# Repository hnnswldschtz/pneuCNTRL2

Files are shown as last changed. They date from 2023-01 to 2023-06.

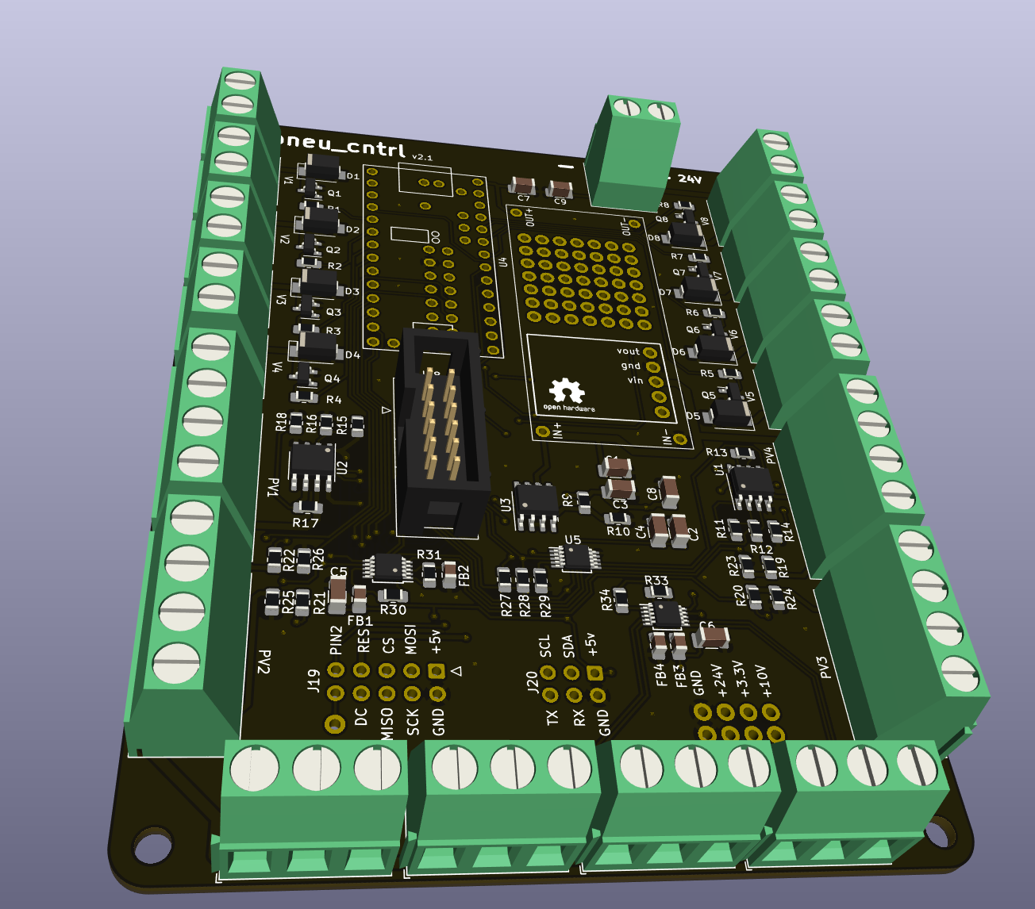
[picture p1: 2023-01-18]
hardware/pneuCNTRL.png

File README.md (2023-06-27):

# pneuCNTRL2 Firmware
8 channel pressure controlled inlation/deflation system for the inflatable haptics experiments

Setup:

- custom PCB released as openhardware under cern-ohl-w v2 license
- based on teensy3.2
- ads1115 for ADC
- MCP4728 for DAC
- 4x festo 571482 pressure sensors
- 4x smc 5/3 electric valves
- 4x Festo proportional piezo valves (VEAB-L-26-D7-Q4-V1-1R1)
- LCD i2c display

pneuCNTRL

libraries used:
ADS1115_lite: https://github.com/terryjmyers/ADS1115-Lite
Adafruit_MCP4728: https://github.com/adafruit/Adafruit_MCP4728
Adafruit_NeoPixel: https://github.com/adafruit/Adafruit_NeoPixel
LiquidCrystal_I2C: https://github.com/johnrickman/LiquidCrystal_I2C -> this gives a massive delay when used! maybe avoid!!
Adafruit_ADS1015: https://github.com/adafruit/Adafruit_ADS1X15

Bauhaus-University Weimar \
hnns 2022

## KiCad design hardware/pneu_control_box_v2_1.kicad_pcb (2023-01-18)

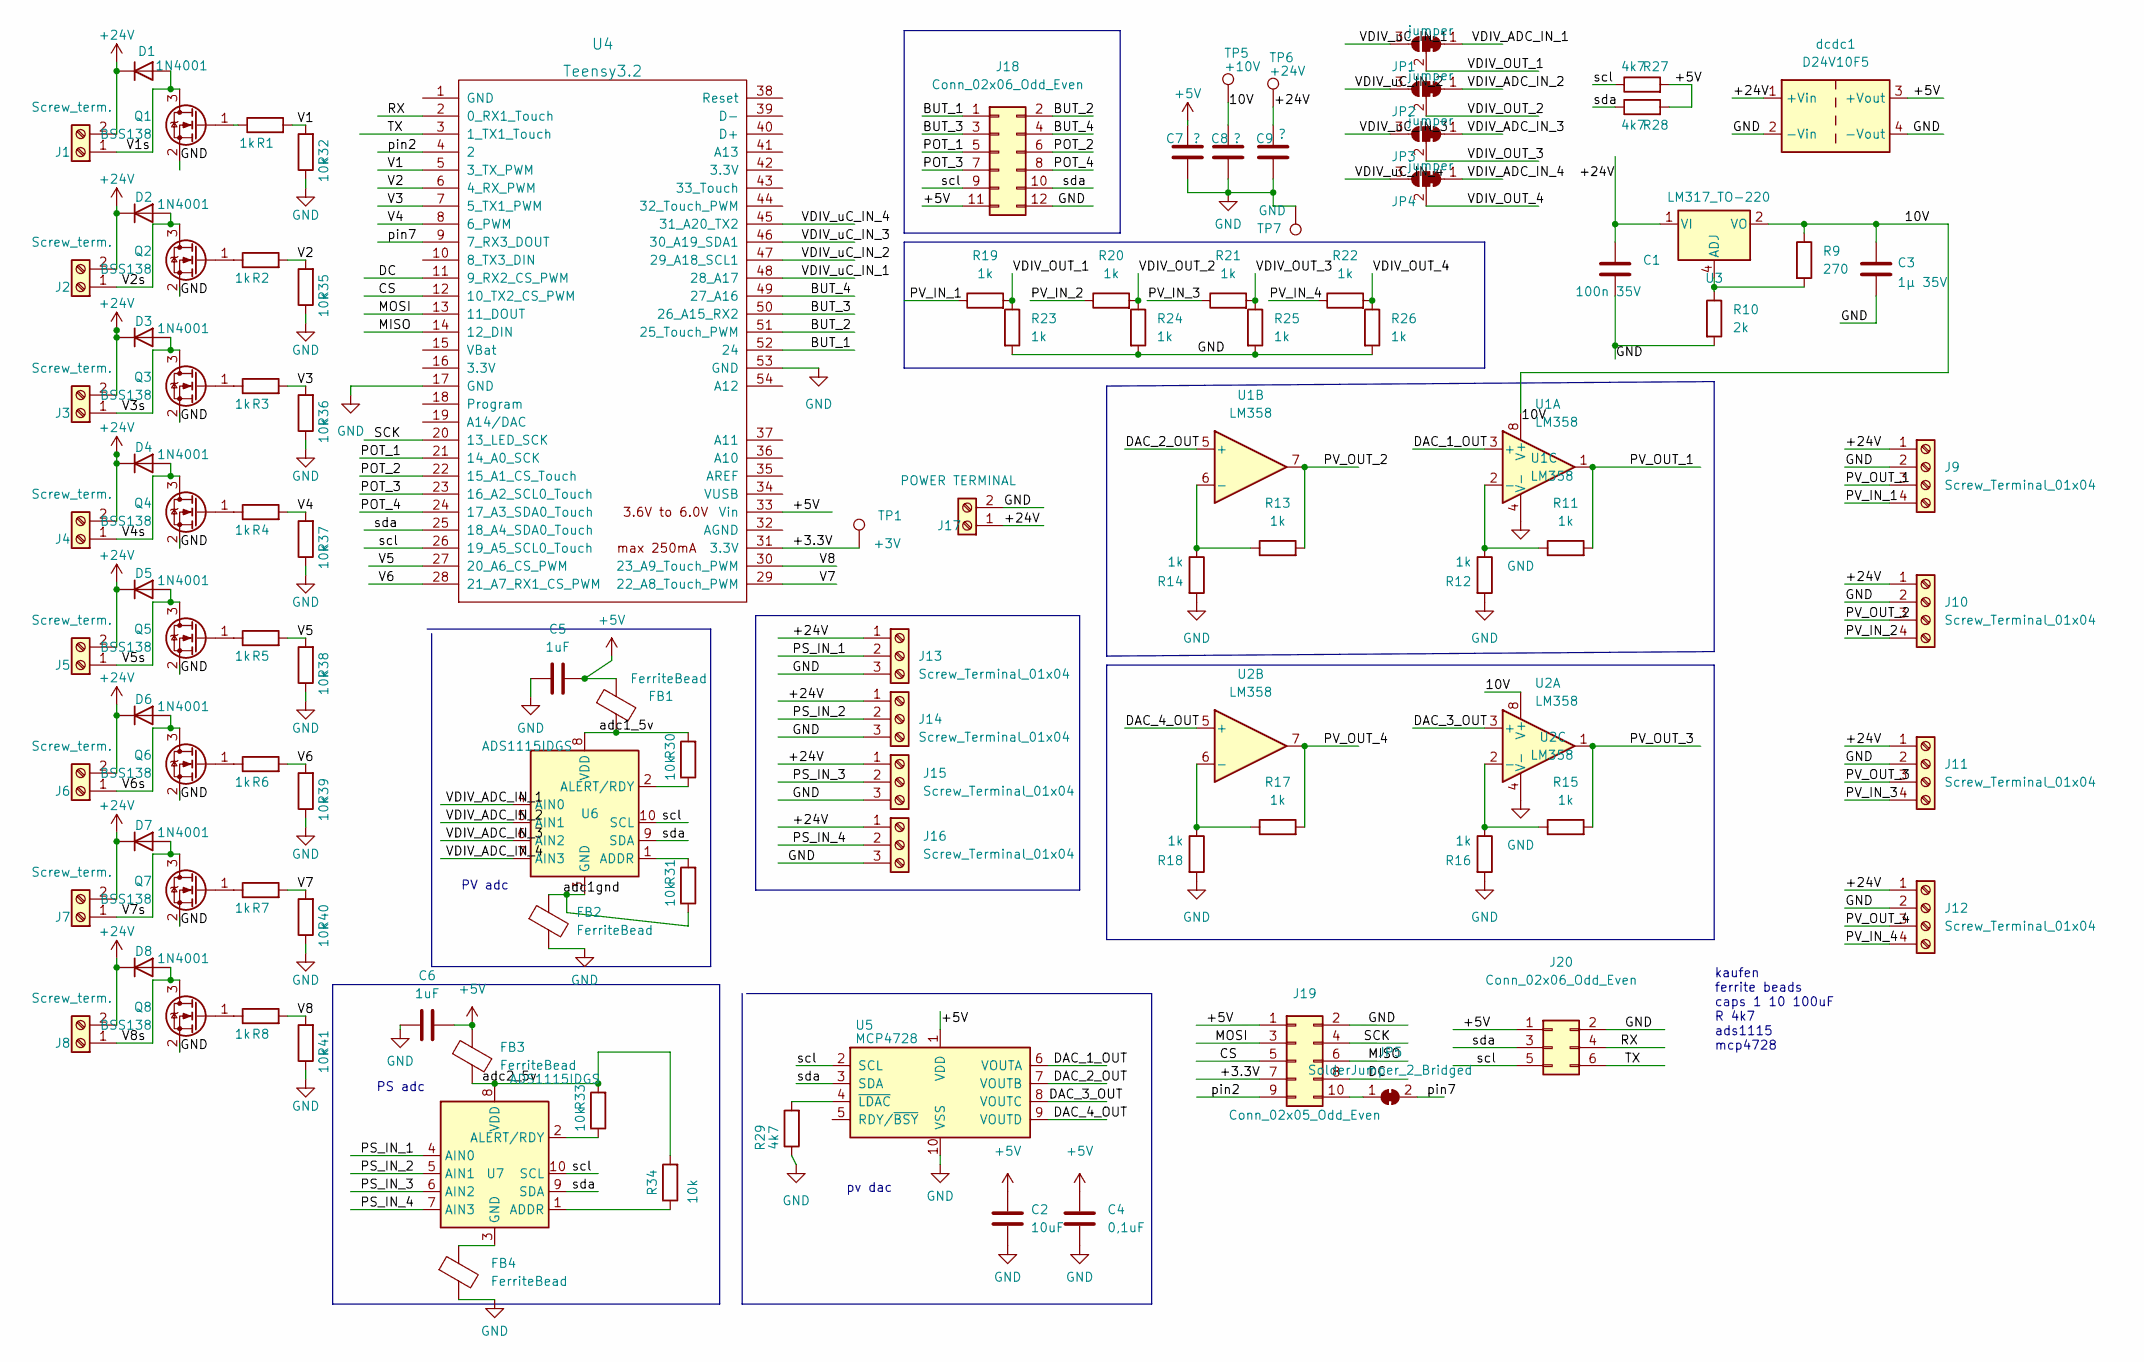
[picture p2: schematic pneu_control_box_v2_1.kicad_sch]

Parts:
C1: 100n 35V; C_1206_3216Metric
C2: 10uF; C_1206_3216Metric
C3: 1µ 35V; C_1206_3216Metric
C4: 0,1uF; C_1206_3216Metric
C5, C6: 1uF; C_1206_3216Metric
C7, C8, C9: ?; C_1206_3216Metric
D1, D2, D3, D4, D5, D6, D7, D8: 1N4001; D_SMA
FB1, FB2, FB3, FB4: FerriteBead; C_0805_2012Metric_Pad1.18x1.45mm_HandSolder
J1, J2, J3, J4, J5, J6, J7, J8: Screw_term.; TerminalBlock_Phoenix_MKDS-1,5-2_1x02_P5.00mm_Horizontal
J9, J10, J11, J12: Screw_Terminal_01x04; TerminalBlock_Phoenix_MKDS-1,5-4_1x04_P5.00mm_Horizontal
J13, J14, J15, J16: Screw_Terminal_01x04; TerminalBlock_Phoenix_MKDS-1,5-3_1x03_P5.00mm_Horizontal
J17: POWER TERMINAL; TerminalBlock_Phoenix_MKDS-1,5-2_1x02_P5.00mm_Horizontal
J18: Conn_02x06_Odd_Even; IDC-Header_2x06_P2.54mm_Vertical
J19: Conn_02x05_Odd_Even; IDC-Header_2x05_P2.54mm_Vertical
J20: Conn_02x06_Odd_Even; IDC-Header_2x03_P2.54mm_Vertical
JP1, JP2, JP3, JP4: jumper; SolderJumper-3_P1.3mm_Bridged12_Pad1.0x1.5mm
JP5: SolderJumper_2_Bridged; SolderJumper-2_P1.3mm_Bridged2Bar_Pad1.0x1.5mm
Q1, Q2, Q3, Q4, Q5, Q6, Q7, Q8: BSS138; SOT-23
R1, R2, R3, R4, R5, R6, R7, R8, R11, R12, R13, R14, R15, R16, R17, R18, R19, R20, R21, R22, R23, R24, R25, R26: 1k; R_0805_2012Metric_Pad1.20x1.40mm_HandSolder
R9: 270; R_0805_2012Metric_Pad1.20x1.40mm_HandSolder
R10: 2k; R_0805_2012Metric_Pad1.20x1.40mm_HandSolder
R27, R28, R29: 4k7; R_0805_2012Metric_Pad1.20x1.40mm_HandSolder
R30, R31, R32, R33, R34, R35, R36, R37, R38, R39, R40, R41: 10k; R_0805_2012Metric_Pad1.20x1.40mm_HandSolder
TP1: +3V; Pin_D1.0mm_L10.0mm
TP5: +10V; Pin_D1.0mm_L10.0mm
TP6: +24V; Pin_D1.0mm_L10.0mm
TP7: GND; Pin_D1.0mm_L10.0mm
U1, U2: LM358; SOIC-8_3.9x4.9mm_P1.27mm
U3: LM317_TO-220; SOIC-8_3.9x4.9mm_P1.27mm
U4: Teensy3.2; Teensy30_31_32_All_Pins
U5: MCP4728; MSOP-10_3x3mm_P0.5mm
U6, U7: ADS1115IDGS; TSSOP-10_3x3mm_P0.5mm
dcdc1: D24V10F5; LM2596 DC-DC

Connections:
+5V: C2.1, C4.1, C5.2, C6.2, C7.1, FB1.1, FB3.1, J18.11, J19.1, J20.1, R27.2, R28.2, U4.33 (Vin), U5.1 (VDD), dcdc1.3 (+Vout)
+24V: C1.1, C9.1, D1.1 (K), D2.1 (K), D3.1 (K), D4.1 (K), D5.1 (K), D6.1 (K), D7.1 (K), D8.1 (K), J1.2, J2.2, J3.2, J4.2, J5.2, J6.2, J7.2, J8.2, J9.1, J10.1, J11.1, J12.1, J13.1, J14.1, J15.1, J16.1, J17.1, TP6.1, U3.1 (VI), dcdc1.1 (+Vin); also elsewhere on the board
/10V: C3.1, C8.1, R9.1, TP5.1, U1.8 (V+), U2.8 (V+), U3.2 (VO), U3.3 (VI), U3.6 (VI), U3.7 (VI); also elsewhere on the board
/+3.3V: J19.7, TP1.1, U4.31 (3.3V); also elsewhere on the board
/BUT_1: J18.1, U4.52 (24)
/BUT_2: J18.2, U4.51 (25_Touch_PWM)
/BUT_3: J18.3, U4.50 (26_A15_RX2)
/BUT_4: J18.4, U4.49 (27_A16)
/CS: J19.5, U4.12 (10_TX2_CS_PWM)
/DAC_1_OUT: U1.3 (+), U5.6 (VOUTA)
/DAC_2_OUT: U1.5 (+), U5.7 (VOUTB)
/DAC_3_OUT: U2.3 (+), U5.8 (VOUTC)
/DAC_4_OUT: U2.5 (+), U5.9 (VOUTD)
/DC: J19.8, U4.11 (9_RX2_CS_PWM)
/MISO: J19.6, U4.14 (12_DIN)
/MOSI: J19.3, U4.13 (11_DOUT)
/POT_1: J18.5, U4.21 (14_A0_SCK)
/POT_2: J18.6, U4.22 (15_A1_CS_Touch)
/POT_3: J18.7, U4.23 (16_A2_SCL0_Touch)
/POT_4: J18.8, U4.24 (17_A3_SDA0_Touch)
/PS_IN_1: J13.2, U7.4 (AIN0)
/PS_IN_2: J14.2, U7.5 (AIN1)
/PS_IN_3: J15.2, U7.6 (AIN2)
/PS_IN_4: J16.2, U7.7 (AIN3)
/PV_IN_1: J9.4, R19.1
/PV_IN_2: J10.4, R20.1
/PV_IN_3: J11.4, R21.1
/PV_IN_4: J12.4, R22.1
/PV_OUT_1: J9.3, R11.2, U1.1
/PV_OUT_2: J10.3, R13.2, U1.7
/PV_OUT_3: J11.3, R15.2, U2.1
/PV_OUT_4: J12.3, R17.2, U2.7
/RX: J20.4, U4.2 (0_RX1_Touch)
/SCK: J19.4, U4.20 (13_LED_SCK)
/TX: J20.6, U4.3 (1_TX1_Touch)
/V1: R1.2, R32.2, U4.5 (3_TX_PWM)
/V1s: D1.2 (A), J1.1, Q1.3 (D)
/V2: R2.2, R35.2, U4.6 (4_RX_PWM)
/V2s: D2.2 (A), J2.1, Q2.3 (D)
/V3: R3.2, R36.2, U4.7 (5_TX1_PWM)
/V3s: D3.2 (A), J3.1, Q3.3 (D)
/V4: R4.2, R37.2, U4.8 (6_PWM)
/V4s: D4.2 (A), J4.1, Q4.3 (D)
/V5: R5.2, R38.2, U4.27 (20_A6_CS_PWM)
/V5s: D5.2 (A), J5.1, Q5.3 (D)
/V6: R6.2, R39.2, U4.28 (21_A7_RX1_CS_PWM)
/V6s: D6.2 (A), J6.1, Q6.3 (D)
/V7: R7.2, R40.2, U4.29 (22_A8_Touch_PWM)
/V7s: D7.2 (A), J7.1, Q7.3 (D)
/V8: R8.2, R41.2, U4.30 (23_A9_Touch_PWM)
/V8s: D8.2 (A), J8.1, Q8.3 (D)
/VDIV_ADC_IN_1: JP1.1 (A), U6.4 (AIN0)
/VDIV_ADC_IN_2: JP2.1 (A), U6.5 (AIN1)
/VDIV_ADC_IN_3: JP3.1 (A), U6.6 (AIN2)
/VDIV_ADC_IN_4: JP4.1 (A), U6.7 (AIN3)
/VDIV_OUT_1: JP1.2 (C), R19.2, R23.1
/VDIV_OUT_2: JP2.2 (C), R20.2, R24.1
/VDIV_OUT_3: JP3.2 (C), R21.2, R25.1
/VDIV_OUT_4: JP4.2 (C), R22.2, R26.1
/VDIV_uC_IN_1: JP1.3 (B), U4.48 (28_A17)
/VDIV_uC_IN_2: JP2.3 (B), U4.47 (29_A18_SCL1)
/VDIV_uC_IN_3: JP3.3 (B), U4.46 (30_A19_SDA1)
/VDIV_uC_IN_4: JP4.3 (B), U4.45 (31_A20_TX2)
/adc1_5v: FB1.2, R30.2, U6.8 (VDD)
/adc1gnd: FB2.1, R31.1, U6.3 (GND)
/adc2_5v: FB3.2, R33.2, R34.2, U7.8 (VDD)
/pin2: J19.9, U4.4 (2)
/pin7: JP5.2 (B), U4.9 (7_RX3_DOUT)
/scl: J18.9, J20.5, R27.1, U4.26 (19_A5_SCL0_Touch), U5.2 (SCL), U6.10 (SCL), U7.10 (SCL)
/sda: J18.10, J20.3, R28.1, U4.25 (18_A4_SDA0_Touch), U5.3 (SDA), U6.9 (SDA), U7.9 (SDA)
GND: C1.2, C2.2, C3.2, C4.2, C5.1, C6.1, C7.2, C8.2, C9.2, FB2.2, FB4.2, J9.2, J10.2, J11.2, J12.2, J13.3, J14.3, J15.3, J16.3, J17.2, J18.12, J19.2, J20.2, Q1.2 (S), Q2.2 (S), Q3.2 (S), Q4.2 (S), Q5.2 (S), Q6.2 (S), Q7.2 (S), Q8.2 (S), R10.2, R12.2, R14.2, R16.2, R18.2, R23.2, R24.2, R25.2, R26.2, R29.1, R32.1, R35.1, R36.1, R37.1, R38.1, R39.1, R40.1, R41.1, TP7.1, U1.4 (V-), U2.4 (V-), U4.17 (GND), U4.53 (GND), U5.10 (VSS), dcdc1.2 (-Vin), dcdc1.4 (-Vout); also elsewhere on the board
unnamed: FB4.1, U7.3 (GND)
unnamed 72: J19.10, JP5.1 (A); also elsewhere on the board
unnamed: Q1.1 (G), R1.1
unnamed: Q2.1 (G), R2.1
unnamed: Q3.1 (G), R3.1
unnamed: Q4.1 (G), R4.1
unnamed: Q5.1 (G), R5.1
unnamed: Q6.1 (G), R6.1
unnamed: Q7.1 (G), R7.1
unnamed: Q8.1 (G), R8.1
unnamed: R9.2, R10.1, U3.4 (ADJ)
unnamed: R11.1, R12.1, U1.2 (-)
unnamed: R13.1, R14.1, U1.6 (-)
unnamed: R15.1, R16.1, U2.2 (-)
unnamed: R17.1, R18.1, U2.6 (-)
unnamed: R29.2, U5.4 (~LDAC)
unnamed: R30.1, U6.2 (ALERT/RDY)
unnamed: R31.2, U6.1 (ADDR)
unnamed: R33.1, U7.2 (ALERT/RDY)
unnamed: R34.1, U7.1 (ADDR)

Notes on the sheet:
kaufen ferrite beads caps 1 10 100uF R 4k7 ads1115 mcp4728
PS adc
pv dac
PV adc

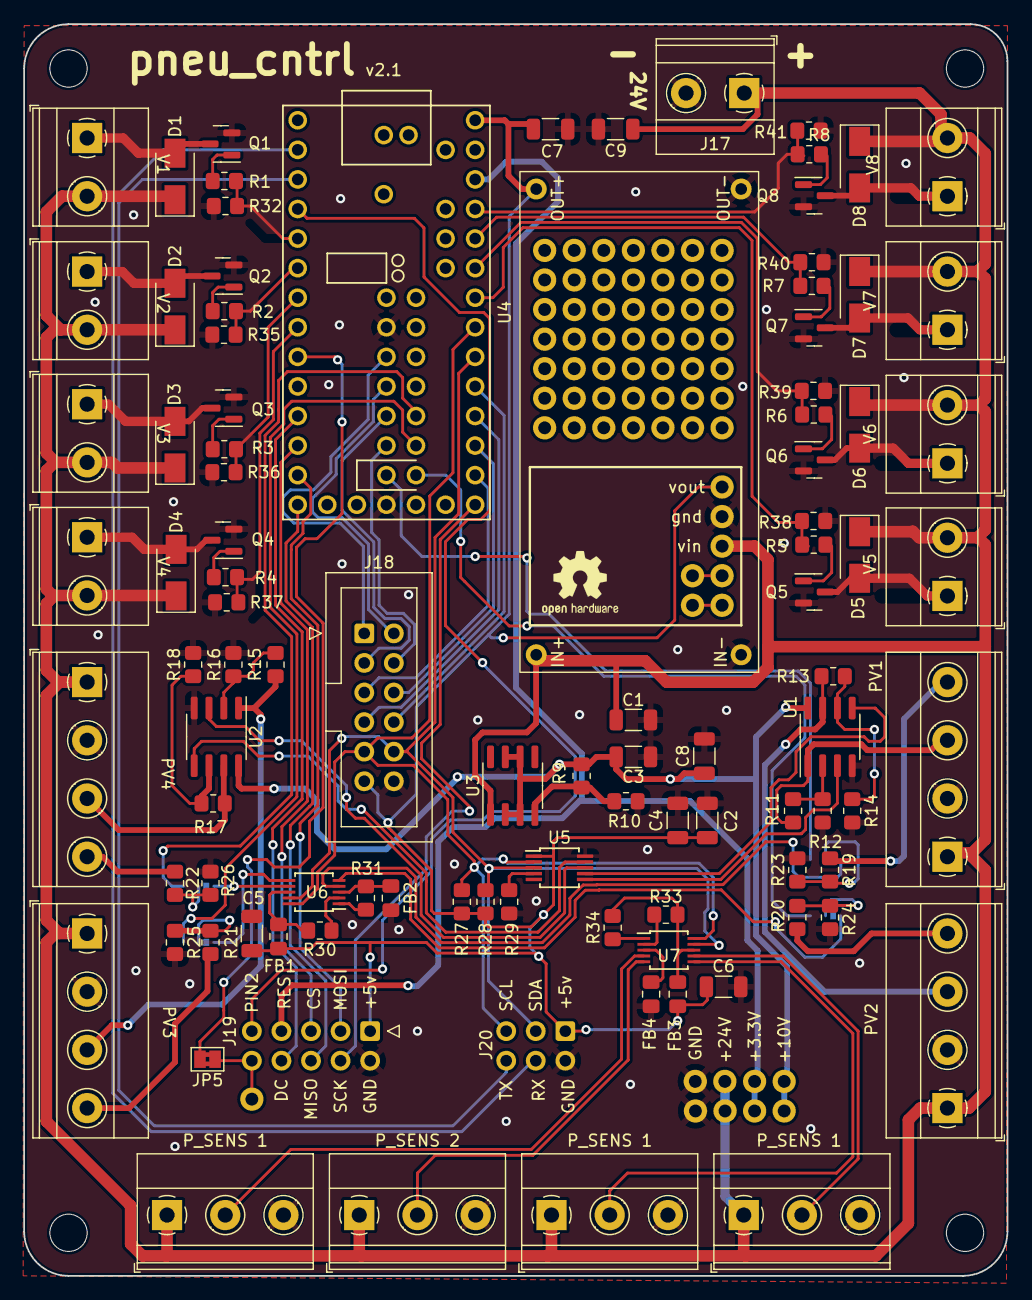
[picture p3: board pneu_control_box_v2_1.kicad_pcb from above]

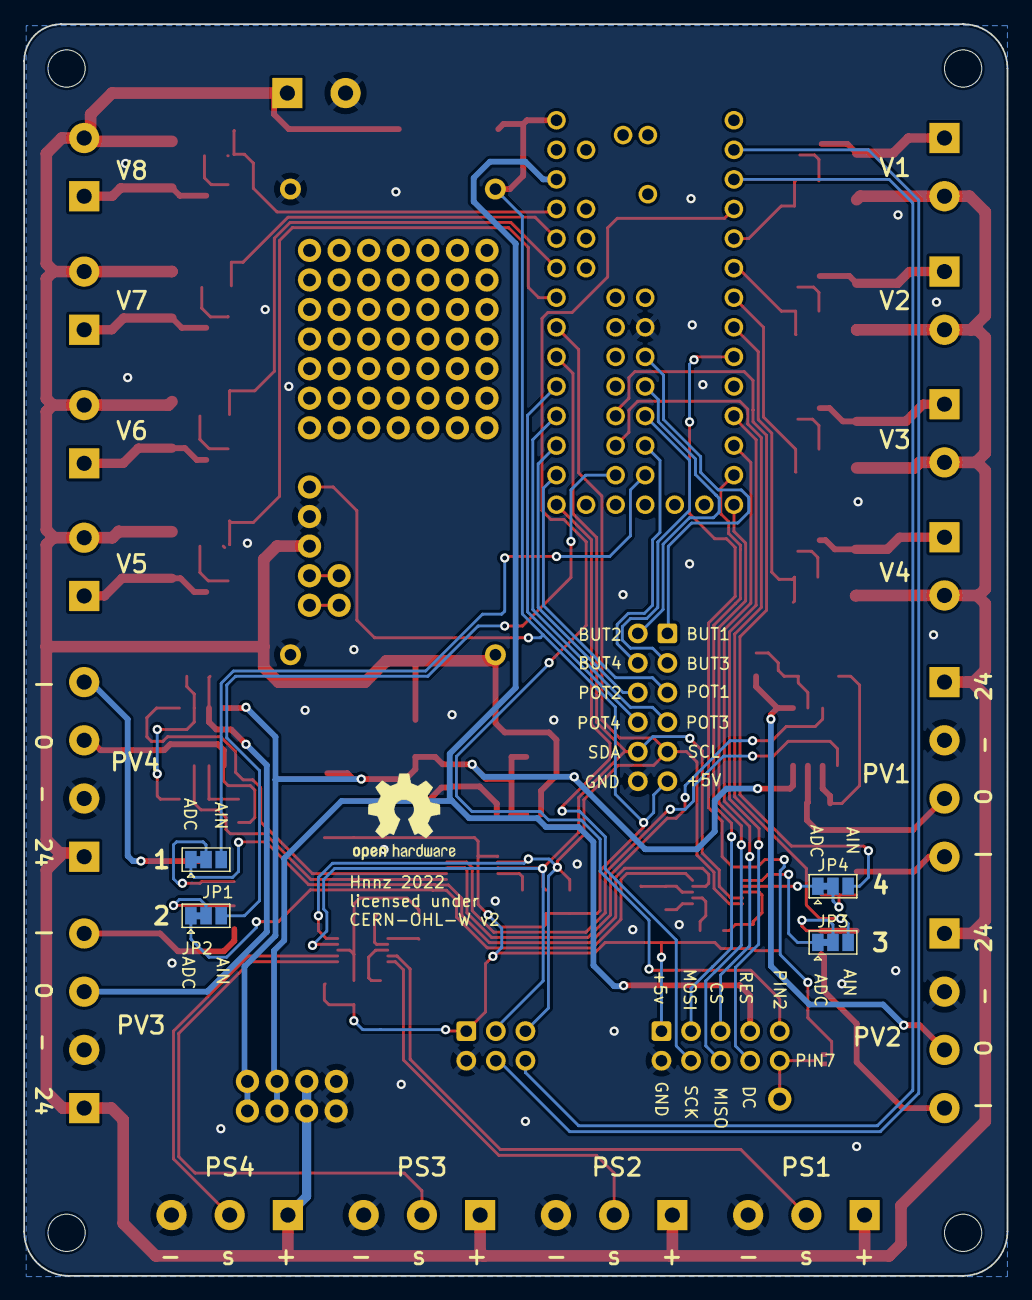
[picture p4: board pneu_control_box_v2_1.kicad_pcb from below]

Board: 2 copper layers, 84.5 x 107.5 mm, 166 parts (4 on the bottom side), 91 nets.

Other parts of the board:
TP6#2: +24V; Pin_D1.0mm_L10.0mm
p, p1, p2, p3, p4, p5, p6, p7, p8, p9, p10, p11, p12, p13, p14, p15, p16, p17, p18, p19, p20, p21, p22, p23, p24, p25, p26, p27, p28, p29, p30, p31, p32, p33, p34, p35, p36, p37, p38, p39, p40, p41, p42, p43, p44, p45, p46, p47, p48, p49, p50, p51, p52, p53, p54: solderPin; Pin_D1.0mm_L10.0mm
p#2, p#3, p#4: solderPin; Pin_D1.0mm_L10.0mm

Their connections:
+24V: TP6#2.1, p49.1; also elsewhere on the board
/10V: p51.1; also elsewhere on the board
/+3.3V: p50.1; also elsewhere on the board
GND: p#3.1; also elsewhere on the board
unnamed 72: p.1; also elsewhere on the board

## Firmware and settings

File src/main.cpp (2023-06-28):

/*
pneuCNTRlbox Firmware.
copyright hnnz 2023

GPL-3.0-or-later

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

*/

#include "PneuCNTRL.h"
//#include <ADS1115_lite.h>

// either manual mode or sequence mode
#define MANUAL_MODE false
#define ADS_L false

LiquidCrystal_I2C lcd(0x27, 16, 2); // Set the LCD address to 0x27 for a 16 chars and 2 line display
Adafruit_NeoPixel switch_neo_pixels(NEO_SWITCH_NUM_PIXELS, NEO_SWITCH_PIN, NEO_GRB + NEO_KHZ800);

#if ADS_L
  ADS1115_lite Psens_adc(0x49);
  ADS1115_lite PV_adc(0x48);
#else
  Adafruit_ADS1115 Psens_adc; // instance of ads1115 Psens_adc  out of all scopes
  Adafruit_ADS1115 PV_adc;
#endif
Adafruit_MCP4728 PV_dac;


Button Button_switcher;


// class ADCtest{
//
// private:
//
//   Adafruit_ADS1115 * adc;
//
// public:
//   ADCtest(Adafruit_ADS1115 * _adc){
//   adc = _adc;
//   adc->setGain(GAIN_TWO);
//   adc->begin();
//   }
//   int readADC(){
//     int pressure = adc->readADC_SingleEnded(1);
//     return pressure;
//   }
//
// };


/* ValveChannel Class Constructor,
Takes 6 Arguments Inflate Valve pin, deflate valve pin, adafruit ads1115 adc,
ads1115 input ch, potentiometer pin, button pin
returns ?
*/

// --------- all four buttons are acivated in manual mode
// #if MANUAL_MODE==true
//     ValveChannel ch1(valve_A1, valve_A2, &Psens_adc, SENSE_PIN_1, POTI_1, BUTTON_1); //instance of channel
// // --------- button 1 is for switching sets in sequencer change init to button_2 to enable interrupt on button_1
// #elif MANUAL_MODE==false
//     ValveChannel ch1(valve_A1, valve_A2, &Psens_adc, SENSE_PIN_1, POTI_1, BUTTON_2); //instance of channel
// #endif
//
// ValveChannel ch2(valve_B3, valve_B4, &Psens_adc, SENSE_PIN_2, POTI_2, BUTTON_2);
// ValveChannel ch3(valve_C5, valve_C6, &Psens_adc, SENSE_PIN_3, POTI_3, BUTTON_3);
// ValveChannel ch4(valve_D7, valve_D8, &Psens_adc, SENSE_PIN_4, POTI_4, BUTTON_4);


#if MANUAL_MODE==true
  ValveChannel ch1(valve_A1, valve_A2, POTI_1, BUTTON_1); //instance of channel
// --------- button 1 is for switching sets in sequencer change init to button_2 to enable interrupt on button_1
#elif MANUAL_MODE==false
  ValveChannel ch1(valve_A1, valve_A2, POTI_1, BUTTON_2); //instance of channel
#endif

ValveChannel ch2(valve_B3, valve_B4, POTI_2, BUTTON_2);
ValveChannel ch3(valve_C5, valve_C6, POTI_3, BUTTON_3);
ValveChannel ch4(valve_D7, valve_D8, POTI_4, BUTTON_4);

ValveChannel * vArray[]= {&ch1, &ch2, &ch3, &ch4};

ProportionalChannel ch5P;
ProportionalChannel ch6P;
ProportionalChannel ch7P;


int knobVal[4];
int old_knobVal[4];
int butVal[4];
int old_butVal[4];
//boolean knobTurned[4];
int page = 0;
int trig = 0;
int count = -1;
unsigned long triggerMetro;
boolean button = false;
boolean startup = true;

unsigned long ledOnTime = 0;
boolean showIt = false;
boolean lightsOut = false;
unsigned long brightFadeTime = 0;
byte brightness;
boolean fading  = false;

/*
DATA_P dataPoint_1 = {100, 100, 50, 50};
DATA_P dataPoint_2 = {10, 5, 60, 60};
DATA_P dataPoint_3 = {20, 20, 70, 70};
DATA_P dataPoint_4 = {15, 20, 80, 80};
DATA_P dataPoint_5 = {10, 30, 90, 90};
DATA_P dataPoint_6 = {20, 30, 100, 100};
DATA_P dataPoint_7 = {10, 10, 5, 00};
DATA_P dataPoint_8 = {3, 3, 6, 10};
DATA_P dataPoint_9 = {20, 20, 15, 20};
DATA_P dataPoint_10 = {20, 20, 20, 30};
DATA_P dataPoint_11 = {20, 20, 30, 40};
DATA_P sequence [] = {dataPoint_1, dataPoint_2, dataPoint_3, dataPoint_4, dataPoint_5, dataPoint_6, dataPoint_7, dataPoint_8, dataPoint_9, dataPoint_10, dataPoint_11};
*/


/* MARCH 2022:
how does your bankaccount feel?
connected:
ch 1: Haptic Baguett (core)
ch 2: Flute
ch 3: Haptic Pattern 1
ch 4: Haptic Pattern 2
ch 5P: BIG BAG
ch 6P: test Flute/notn
*/



SEQ_CH ch1_seq = {32, 57, 99, 18,  10,  6 };//ch 1: Haptic Baguett (core)
SEQ_CH ch2_seq = {32, 57, 99, 18,  9,  0 };//ch 2: Flute
SEQ_CH ch3_seq = { 0, 20, 99,  0,  0,  0 };//ch 3: Haptic Pattern 1
SEQ_CH ch4_seq = {70, 99, 99, 37, 25,  0 };//ch 4: Haptic Pattern 2
SEQ_CH ch5_seq = {32, 57, 99, 18,  6,  0 };//ch 5P: BIG BAG
SEQ_CH ch6_seq = {32, 57, 99, 18,  9,  0 };//ch 6P: test Flute/notn


// DATA_P dataPoint_1 = {32, 32,  0,  70, 32, 32};
// DATA_P dataPoint_2 = {57, 57,  20, 99, 57, 57};
// DATA_P dataPoint_3 = {99, 99,  99, 99, 99, 99};
// DATA_P dataPoint_4 = {18, 18,   0, 37, 18, 18}; // was 34/73
// DATA_P dataPoint_5 = {12,  9,   0, 25,  6,  9}; // set to nine to reach 12
// DATA_P dataPoint_6 = { 8,  0,   0,  0,  0,  0};

DATA_P dataPoint_1 = {85, 32,  0,  70, 32, 32};
DATA_P dataPoint_2 = {85, 57,  20, 99, 57, 57};
DATA_P dataPoint_3 = {85, 99,  99, 99, 99, 99};
DATA_P dataPoint_4 = {85, 18,   0, 37, 18, 18}; // was 34/73
DATA_P dataPoint_5 = {85,  10,   0, 25,  6,  9}; // set to nine to reach 12
DATA_P dataPoint_6 = {85,  0,   0,  0,  0,  0};

DATA_P sequence [] = {dataPoint_1, dataPoint_2, dataPoint_3, dataPoint_4, dataPoint_5, dataPoint_6};
//DATA_P sequence[4];

#define SEQ_LNGTH int((sizeof sequence)/sizeof(*sequence))  // calc sequence length

/*
BE CAREFULL!!!
A WRONG SETTING CAUSES YOUR INFLATABLES TO EXPLODE!!!
TESTET WITH 4 Bar Pressure input from Compressor
*/
const long TIMEOUT = 60000;

const int BIGBAG_SAFETY_PRESSURE_LIMIT = 17500; //where safety kicks in
const int FLUTE_SAFETY_PRESSURE_LIMIT = 17500;//18700; //where safety kicks in
const int BAGUETTE_SAFETY_PRESSURE_LIMIT = 21000; //where safety kicks in
const int MEDIUM_NYLON_SURFACE_STRUCTURE_SAFETY_PRESSURE_LIMIT = 25000; //where safety kicks in
const int SPINACKER_STRUCTURE_SAFETY_PRESSURE_LIMIT = 19000;//where safety kicks in

//ADCtest testADC(&ads);
int prsssr = 0;
unsigned long lastLast = 0;

void setup() {

    switch_neo_pixels.begin();
    Serial.begin(115200);
    delay(1500);
    Serial.println("Hello, I'm here and ready to accept instructions");
    lcd.init();
    lcd.backlight();// Turn on the backlight

    #if ADS_L
      Psens_adc.setGain(ADS1115_REG_CONFIG_PGA_2_048V);
      Psens_adc.setSampleRate(ADS1115_REG_CONFIG_DR_860SPS);
      PV_adc.setGain(ADS1115_REG_CONFIG_PGA_4_096V);
      PV_adc.setSampleRate(ADS1115_REG_CONFIG_DR_860SPS);
    #else
      Psens_adc.setGain(GAIN_TWO); // 2,048V Max. set to two or higher because of spte sensors 1bar ~ 0,5V
      Psens_adc.begin(0x49);

      PV_adc.setGain(GAIN_ONE); // 4,096V max. set to one because of spte sensors 1bar ~ 5V / 2,5V
      PV_adc.begin(0x48);
    #endif



  delay(2000);
  if (!PV_dac.begin()) {
      Serial.println("Failed to find MCP4728 chip");
  }

  // if (!PV_adc.testConnection()) {
  //   Serial.println("PropChanAdc Connection failed"); //oh man...something is wrong
  //   return;
  // }
  // if (!Psens_adc.testConnection()) {
  //   Serial.println("ValvePSens Connection failed"); //oh man...something is wrong
  //   return;
  // }

    pinMode(BUTTON_SWITCH, INPUT_PULLUP);
    //attachInterrupt(BUTTON_SWITCH, setFlagHandler , FALLING);

    //----------- activate BUTTON_1 interrupt when running auto sequencer mode
#if MANUAL_MODE==false
    pinMode(BUTTON_1, INPUT_PULLUP);
    //attachInterrupt(BUTTON_1, setFlagHandler , FALLING);
#endif
    //---------------
  //  pinMode(SWITCH_LED, OUTPUT);
  #if ADS_L
    ch1.setAdc(&Psens_adc, ADS1115_REG_CONFIG_MUX_SINGLE_0);
    ch2.setAdc(&Psens_adc, ADS1115_REG_CONFIG_MUX_SINGLE_1);
    ch3.setAdc(&Psens_adc, ADS1115_REG_CONFIG_MUX_SINGLE_2);
    ch4.setAdc(&Psens_adc, ADS1115_REG_CONFIG_MUX_SINGLE_3);
  #else
    ch1.setAdc(&Psens_adc, SENSE_PIN_1);
    ch2.setAdc(&Psens_adc, SENSE_PIN_2);
    ch3.setAdc(&Psens_adc, SENSE_PIN_3);
    ch4.setAdc(&Psens_adc, SENSE_PIN_4);
  #endif

    //VALVE CHANNELS
      //arguments:  min_pressure, max_pressure, safety_stop_pressure, timeout
    ch1.begin(15500,BIGBAG_SAFETY_PRESSURE_LIMIT-250,BIGBAG_SAFETY_PRESSURE_LIMIT,TIMEOUT); // lower and upper pressure vals are experimentally derived from Psens_adc wset to ads.setGain(GAIN_TWO);

    ch2.begin(15500,FLUTE_SAFETY_PRESSURE_LIMIT-250,FLUTE_SAFETY_PRESSURE_LIMIT, TIMEOUT);//(15500,MEDIUM_NYLON_SURFACE_STRUCTURE_SAFETY_PRESSURE_LIMIT-250,MEDIUM_NYLON_SURFACE_STRUCTURE_SAFETY_PRESSURE_LIMIT);

    ch3.begin(15500,BAGUETTE_SAFETY_PRESSURE_LIMIT-250,BAGUETTE_SAFETY_PRESSURE_LIMIT, TIMEOUT);//(15500,LENKRAD_SAFETY_PRESSURE_LIMIT-250,LENKRAD_SAFETY_PRESSURE_LIMIT);

    ch4.begin(15500,BAGUETTE_SAFETY_PRESSURE_LIMIT-250,BAGUETTE_SAFETY_PRESSURE_LIMIT, TIMEOUT);
    //delay(10000);
    /*set hysteresis boundarys according to used air chamber size and flexibility
    the bigger the air chamber, the lower the values
    */
    ch1.setInertia(20,10);
    ch2.setInertia(20,10);
    ch3.setInertia(20,10);
    ch4.setInertia(20,10);


    /*//value range for displayed in GUI */
    // ch1.setGuiMappingRange(0,100);
    // ch2.setGuiMappingRange(0,100);
    // ch3.setGuiMappingRange(0,100);
    // ch4.setGuiMappingRange(0,100);


// PROPORITIONAL CHANNELS 

  //test valves

  //ch5P.setAdc(&PV_adc,3); //ADS1115_REG_CONFIG_MUX_SINGLE_3);
  //ch6P.setAdc(&PV_adc,2); //ADS1115_REG_CONFIG_MUX_SINGLE_2);
  //ch7P.setAdc(&PV_adc,0); //ADS1115_REG_CONFIG_MUX_SINGLE_0);



  #if ADS_L
    ch5P.setAdc(&PV_adc,ADS1115_REG_CONFIG_MUX_SINGLE_3);
    ch6P.setAdc(&PV_adc,ADS1115_REG_CONFIG_MUX_SINGLE_2);
    ch7P.setAdc(&PV_adc,ADS1115_REG_CONFIG_MUX_SINGLE_0);
  #else
    ch5P.setAdc(&PV_adc,3);
    ch6P.setAdc(&PV_adc,2);
    ch7P.setAdc(&PV_adc,0);
  #endif

  ch5P.setDac(&PV_dac, MCP4728_CHANNEL_D);
  ch6P.setDac(&PV_dac, MCP4728_CHANNEL_C);
  ch7P.setDac(&PV_dac, MCP4728_CHANNEL_A);


  /* ------------ begin and set pressure range and limits of the connected inflateble
  takes three arguemnts, Lower end of pressure, upper end, safety limit and pressure range in Bar of valve (default = 1).
  pressure value is experimentally derived and revers to voltage levels from PV_adc wset to ads.setGain(GAIN_TWO);
  */
  ch5P.begin(0,10000,10250); // BIGBAG CALIBRATED lower and upper pressure vals are experimentally derived from Psens_adc wset to ads.setGain(GAIN_TWO) (max is 32768);
  ch6P.begin(0,10250,10500);
  ch7P.begin(0,10250,10500,2);  // has fourth argument, to specify the higher pressure Range of the Valve in Bar
}

void loop() {
    //switch_neo_pixels.clear();
  //Serial.println(testADC.readADC());

    if (MANUAL_MODE) { /*________manual mode__________*/
      // set and apply pressure manually
        ch1.operate_manual();
        ch2.operate_manual();
        ch3.operate_manual();
        ch4.operate_manual();

        //read all potis and knobs of first 4 channels
        for (int i = 0;i<4;i++){
          knobVal[i] = vArray[i]->get_Poti();
          butVal[i]=vArray[i]->get_button();
        }

        /*page switcher. Got to page where last change happend*/
        for (int i=0;i<4;i++){
            if ((abs(knobVal[i]-old_knobVal[i])>10)||(butVal[i] != old_butVal[i])) page = i;
            old_knobVal[i] = knobVal[i];
            old_butVal[i] = butVal[i];
        }

        display(page);
        sendDataOverSerial(false); //argument true sets data for serial plotter

    }
    else
    { /*________sequencer mode__________*/
        /*steps through sequence by pressing button 1*/
        // if (digitalRead(BUTTON_1) == LOW) Serial.println("button1 down");
        // if ((Button_switcher.getFlag() && !button) || startup) { //||Button_1.get_buttonNow()
        if (((digitalRead(BUTTON_SWITCH) == LOW || digitalRead(BUTTON_1) == LOW) && !button) || startup) { //||Button_1.get_buttonNow()
            //digitalWrite(SWITCH_LED, HIGH);
            brightness = 255;
          for (int ledNr = 0; ledNr<NEO_SWITCH_NUM_PIXELS; ledNr++){

            switch_neo_pixels.setBrightness(brightness);
            switch_neo_pixels.setPixelColor(ledNr, switch_neo_pixels.Color(0, 255,255));
            switch_neo_pixels.show();
               // Send the updated pixel colors to the hardware.
          }
            //Serial.println("LIGHTS ON");
            ledOnTime = millis();
            startup = false; //makes sure pessures are defined if not risk of burst!!!
            trig = 1;
            button = true;
            lightsOut = false;
            count++;
            if (count >= SEQ_LNGTH) count = 0;

            /*--------------DEBUG MSG---------------*/
            // Serial.print("count: ");
            // Serial.println(count);


            ch5P.goToPressure(sequence[count].ch5_val);
            //ch7P.goToPressure(sequence[count].ch2_val);
            ch7P.goToPressure(0);
            //ch6P.goToPressure(0);
            ch6P.goToPressure(0);

            Serial.print(sequence[count].ch1_val);
            Serial.print(" ");
            Serial.print(sequence[count].ch2_val);
            Serial.print(" ");
            Serial.print(sequence[count].ch3_val);
            Serial.print(" ");
            Serial.print(sequence[count].ch4_val);
            Serial.print(" ");
            Serial.print(sequence[count].ch5_val);
            Serial.print(" ");
            Serial.println(sequence[count].ch6_val);
        }
        else if ((digitalRead(BUTTON_SWITCH) == HIGH && digitalRead(BUTTON_1) == HIGH)  && button && (millis()-ledOnTime >200)) { //&& !Button_1.get_buttonNow()
            button = false;
            lastLast = millis();
            showIt = true;


            //Button_switcher.clearFlag();
        }
        //---------Valve channels-------------
        if ( millis() - triggerMetro > 100 ){
          ch1.trigger(sequence[count].ch1_val, trig);
          ch2.trigger(sequence[count].ch2_val, trig);
          ch3.trigger(sequence[count].ch3_val, trig);
          ch4.trigger(sequence[count].ch4_val, trig);
          ch5P.operate();
          ch6P.operate();
          ch7P.operate();

          triggerMetro = millis();
          trig = 0;
          if (!fading) display_seq_4ch(count);
        }
    }


//-------------- button illumination -----------
    if (millis()-ledOnTime > 2500 && !lightsOut) {
    if (millis()-brightFadeTime > 2){
      fading = true;
        switch_neo_pixels.setBrightness(--brightness);
        switch_neo_pixels.show();   // Send the updated pixel colors to the hardware.
        // Serial.println(brightness);
        if (brightness == 0) {
          lightsOut = true;
          // Serial.println("lightsOut");
          fading = false;
        }
        brightFadeTime = millis();
      }
    }//digitalWrite(SWITCH_LED, LOW); // switch of LED

}

/*
  HELPER Functions
  Display
  serial
*/

/* display fundtion for manual mode*/
void display(int page){

    if (page <2){
        lcd.setCursor(0, 0);
        lcd.print("1 v");
        lcd.print("     ");
        lcd.setCursor(3, 0);
        lcd.print(ch1.get_MappedPoti());

        lcd.setCursor(8, 0);
        lcd.print(" p");
        lcd.print("      ");
        lcd.setCursor(10, 0);
        lcd.print(ch1.get_MappedPressure());
        if (ch1.get_state()) lcd.print(".");
        else lcd.print(" ");

        lcd.setCursor(0, 1);
        lcd.print("2 v");
        lcd.print("     ");
        lcd.setCursor(3, 1);
        lcd.print(ch2.get_MappedPoti());

        lcd.setCursor(8, 1);
        lcd.print(" p");
        lcd.print("      ");
        lcd.setCursor(10, 1);
        lcd.print(ch2.get_MappedPressure());
        if (ch2.get_state()) lcd.print(".");
        else lcd.print(" ");
    }
    else{
        lcd.setCursor(0, 0);
        lcd.print("3 v");
        lcd.print("     ");
        lcd.setCursor(3, 0);
        lcd.print(ch3.get_MappedPoti());

        lcd.setCursor(8, 0);
        lcd.print(" p");
        lcd.print("      ");
        lcd.setCursor(10, 0);
        lcd.print(ch3.get_MappedPressure());
        if (ch3.get_state()) lcd.print(".");
        else lcd.print(" ");

        lcd.setCursor(0, 1);
        lcd.print("4 v");
        lcd.print("     ");
        lcd.setCursor(3, 1);
        lcd.print(ch4.get_MappedPoti());

        lcd.setCursor(8, 1);
        lcd.print(" p");
        lcd.print("      ");
        lcd.setCursor(10, 1);
        lcd.print(ch4.get_MappedPressure());
        if (ch4.get_state()) lcd.print(".");
        else lcd.print(" ");
    }

}

/* display fundtion for sequencer  mode*/
void display_seq_4ch(int count){

    lcd.setCursor(0, 0);
    // lcd.print("v");
    lcd.print("    ");
    lcd.setCursor(0, 0);
    lcd.print(sequence[count].ch1_val);


    lcd.setCursor(0, 1);
    // lcd.print("p");
    lcd.print("    ");
    lcd.setCursor(0, 1);
    lcd.print(ch1.get_MappedPressure());
    if (ch1.get_state()) lcd.print(".");
    else lcd.print(" ");

    lcd.setCursor(3, 0);
    lcd.print("     ");
    lcd.setCursor(4, 0);
    lcd.print(sequence[count].ch2_val);

    lcd.setCursor(3, 1);
    lcd.print("     ");
    lcd.setCursor(4, 1);
    lcd.print(ch2.get_MappedPressure());
    if (ch2.get_state()) lcd.print(".");
    else lcd.print(" ");

    lcd.setCursor(7, 0);
    lcd.print("     ");
    lcd.setCursor(8, 0);
    lcd.print(sequence[count].ch3_val);

    lcd.setCursor(7, 1);
    lcd.print("     ");
    lcd.setCursor(8, 1);
    lcd.print(ch3.get_MappedPressure());
    if (ch3.get_state()) lcd.print(".");
    else lcd.print(" ");

    lcd.setCursor(11, 0);
    lcd.print("     ");
    lcd.setCursor(12, 0);
    lcd.print(sequence[count].ch4_val);

    lcd.setCursor(11, 1);
    lcd.print("     ");
    lcd.setCursor(12, 1);
    lcd.print(ch4.get_MappedPressure());
    if (ch4.get_state()) lcd.print(".");
    else lcd.print(" ");
}


void sendDataOverSerial(boolean plotter){
static unsigned long lastSend = 0;

if (millis()-lastSend > 80){
    lastSend = millis();
    if (!plotter){
        Serial.print("p: ");
        Serial.print("\t");
      }
    Serial.print(ch1.get_MappedPressure());
    Serial.print("\t");
    Serial.print(ch2.get_MappedPressure());
    Serial.print("\t");
    Serial.print(ch3.get_MappedPressure());
    Serial.print("\t");
    Serial.print(ch4.get_MappedPressure());

    if (!plotter){
      Serial.print("\npr:");
      Serial.print("\t");
      Serial.print(ch1.get_Pressure());
      Serial.print("\t");
      Serial.print(ch2.get_Pressure());
      Serial.print("\t");
      Serial.print(ch3.get_Pressure());
      Serial.print("\t");
      Serial.print(ch4.get_Pressure());
      Serial.print("\nv: ");
      Serial.print("\t");
      Serial.print(ch1.get_MappedPoti());
      Serial.print("\t");
      Serial.print(ch2.get_MappedPoti());
      Serial.print("\t");
      Serial.print(ch3.get_MappedPoti());
      Serial.print("\t");
      Serial.print(ch4.get_MappedPoti());
      Serial.print("\n");
    }
    Serial.print("\n");
  }
}

void setFlagHandler(){
  if (!Button_switcher.getFlag()) Button_switcher.setFlag(); //
}


// spte sensors on ch1 - ch4:  1 bar ~ 0,5V
// veab valves on ch5 - ch 6:  1 bar ~ 10v -> spannungsteiler ->5V
// veab valve on ch7:          1 bar ~ 5v -> spannungsteiler -> 2.5V

// The ADC input range (or gain) can be changed via the following
// functions, but be careful never to exceed VDD +0.3V max, or to
// exceed the upper and lower limits if you adjust the input range!
// Setting these values incorrectly may destroy your ADC!
//                                                                ADS1015  ADS1115
//                                                                -------  -------
// ads.setGain(GAIN_TWOTHIRDS);  // 2/3x gain +/- 6.144V  1 bit = 3mV      0.1875mV (default)
// ads.setGain(GAIN_ONE);        // 1x gain   +/- 4.096V  1 bit = 2mV      0.125mV
// ads.setGain(GAIN_TWO);        // 2x gain   +/- 2.048V  1 bit = 1mV      0.0625mV
// ads.setGain(GAIN_FOUR);       // 4x gain   +/- 1.024V  1 bit = 0.5mV    0.03125mV
// ads.setGain(GAIN_EIGHT);      // 8x gain   +/- 0.512V  1 bit = 0.25mV   0.015625mV
// ads.setGain(GAIN_SIXTEEN);    // 16x gain  +/- 0.256V  1 bit = 0.125mV  0.0078125mV

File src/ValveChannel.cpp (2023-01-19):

/*
pneuCNTRlbox Firmware.
copyright hnnz 2023

GPL-3.0-or-later

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

*/
#include "PneuCNTRL.h"
#include "Channels.h"

//public methods

//ValveChannel::ValveChannel(int inf_pin, int def_pin, Adafruit_ADS1115 * _adc, int _adc_ch, int pot_pin, int button_pin){
ValveChannel::ValveChannel(int inf_pin, int def_pin, int pot_pin, int button_pin){

    #define DEBOUNCE_DELAY 30UL


    //Serial.begin(9600);
    infValvePin = inf_pin;
    defValvePin = def_pin;
    potPin = pot_pin;
    buttonPin = button_pin;

    //----default global gui mapping values. std: 0-100
    GUI_pMapMin = 0;
    GUI_pMapMax = 100;


}

int ValveChannel::begin(int min_pressure, int max_pressure, int safety_stop, long _timeout){
    pinMode(infValvePin,OUTPUT);
    pinMode(defValvePin,OUTPUT);
    digitalWrite(infValvePin,LOW);
    digitalWrite(defValvePin,LOW);
    pinMode(buttonPin,INPUT_PULLUP);


    time_out = _timeout;
    minPressure = min_pressure;
    maxPressure = max_pressure;
    safetyStop = safety_stop;

    inflate();
    delay(100);
    deflate();
    delay(100);
    stop();

    //Serial.print("Getting single-ended readings from AIN ");
    //Serial.println (adc_ch);

    return 0;
}

#if ADS_L
  void ValveChannel::setAdc(ADS1115_lite *_adc, int _adc_ch)
  {
    adc = _adc;
    adc_ch = _adc_ch;
  }
#else
  void ValveChannel::setAdc(Adafruit_ADS1115 *_adc, int _adc_ch)
  {
    adc = _adc;
    adc_ch = _adc_ch;
  }
#endif

void ValveChannel::setInertia(int infIn = 1000, int defIn = 500){
  // change hysteresis boundarys according to inflation and defltion behaviour
  inflationInertia = infIn;
  deflationInertia = defIn;
}

void ValveChannel::setGuiMappingRange(int _mapMin, int _mapMax){
  GUI_pMapMin = _mapMin;
  GUI_pMapMax = _mapMax;
}

byte ValveChannel::operate_manual(){
    readPressure();
    emergency_watchdog(safetyStop);
    mapPressureToGui();

    readPotentiometer();
    readButton(DEBOUNCE_DELAY);


    if (millis()-lastFill>=0){

        lastFill=millis();
        if (pressure < potiValMapped && buttonPressed) {
            inflate();
            inFlate = true;
            inFlate_time = millis();
        }
        else if (pressure > (potiValMapped-inflationInertia) && inFlate){
            stop();
            inFlate = false;
        }
        else if (pressure > potiValMapped && buttonPressed) {
            deflate();
            deFlate = true;
            deFlate_time = millis();
        }
        else if (pressure < (potiValMapped+deflationInertia) && deFlate){
            stop();
            deFlate = false;
        }
    }
  if (inFlate&&(millis() - inFlate_time > time_out)) stop();
  if (deFlate&&(millis() - deFlate_time > time_out)) stop();

  return 0;
}

byte ValveChannel::trigger(int p_set, int trig){

    readPressure();
    emergency_watchdog(safetyStop);
    mapPressureToGui();

    int p_set_mapped_to_raw_p = mapToRawP(p_set); // we work internally with the raw input value range from adc

    if (millis()-lastFill>=0){

        lastFill=millis();
        // -------start inflating
        if (old_p_set!=p_set_mapped_to_raw_p&&(pressure < p_set_mapped_to_raw_p && trig == 1)) {
            deFlate = false;
            stop();
            // Serial.print("in, ");
            // Serial.print("p_set: ");
            // Serial.print(p_set);
            // Serial.print(", p_set: ");
            // Serial.print(p_set_mapped_to_raw_p);
            // Serial.print(", pressure: ");
            // Serial.println(pressure);
            inflate();
            inFlate = true;
            inFlate_time = millis();
            old_p_set=p_set_mapped_to_raw_p;
        }
        // ------ stop inflating
        else if (pressure > (p_set_mapped_to_raw_p-calcInflationInertia(pressure)) && inFlate){

            // Serial.print("at ");
            // Serial.print(pressure);
            // Serial.print(" inflation ");
            stop();

            inFlate = false;
        } // -------start deflating
        else if (old_p_set!=p_set_mapped_to_raw_p&&(pressure > p_set_mapped_to_raw_p && trig == 1)) {
            inFlate = false;
            stop();
            // Serial.print("out, ");
            // Serial.print("p_set: ");
            // Serial.print(p_set);
            // Serial.print(", p_set: ");
            // Serial.print(p_set_mapped_to_raw_p);
            // Serial.print(", pressure: ");
            // Serial.println(pressure);
            deflate();
            deFlate = true;
            deFlate_time = millis();
            old_p_set=p_set_mapped_to_raw_p;
        }

        //------ stop deflating
        else if (pressure < (p_set_mapped_to_raw_p-deflationInertia) && deFlate ){

          // Serial.print("at ");
          // Serial.print(pressure);
          // Serial.print(" deflation ");
          if (p_set_mapped_to_raw_p != 0) stop(); // dont close valve when val is set to zero
            deFlate = false;
        }
    }
    //timeout if inflation never reaches top
    if (inFlate && (millis() - inFlate_time > time_out)) {
        Serial.println ("timeout_inF ");
        inFlate=false;
        stop();
    }
    //timeout if inflation never reaches bottom
    if (deFlate&&(millis() - deFlate_time>time_out)) {
        Serial.println ("timeout_deF ");
        deFlate=false;
        stop();
    }

    /*REFILL i pressure fals lower then calculated offset to set pressure
    might probably collide with timeout inflation control
    */
    if ((!inFlate&&!deFlate)&&(pressure < (p_set_mapped_to_raw_p-calcRefillOffset(pressure)) && trig == 0)){
      //if (millis()-deFlate_time>100){
         // Serial.print("Refill offset: ");
         // Serial.println(calcRefillOffset(pressure));
        // Serial.println(" deflation ");
          deFlate = false;
          inflate();
          inFlate = true;
          inFlate_time = millis();
        //}
    }

    // if ((!inFlate&&!deFlate)&&(pressure > (p_set_mapped_to_raw_p+calcRefillOffset(pressure)) && trig == 0)) {
    //   if (millis()-inFlate_time>500){
    //    Serial.print("Refill offset: ");
    //    Serial.println(calcRefillOffset(pressure));
    //   // Serial.println(" deflation ");
    //     inFlate = false;
    //     deflate();
    //     deFlate = true;
    //     deFlate_time = millis();
    //   }
    // }

  return 0;
}
int ValveChannel::mapToRawP(int p){ // maps pressure setting from GUI land to internal adc raw value
  return int(map(p,GUI_pMapMin,GUI_pMapMax,minPressure,maxPressure));
}
int ValveChannel::calcRefillOffset(int p){
  return (p-minPressure)/10; // add some hysteresis
}

int ValveChannel::calcInflationInertia(int p){
  return (p-minPressure)/20;
}
void ValveChannel::mapPressureToGui(){ // maps pressuref from internal adc raw value to GUI land pressure range
    mappedPressure = int(map(pressure,minPressure,maxPressure,GUI_pMapMin,GUI_pMapMax));
}
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

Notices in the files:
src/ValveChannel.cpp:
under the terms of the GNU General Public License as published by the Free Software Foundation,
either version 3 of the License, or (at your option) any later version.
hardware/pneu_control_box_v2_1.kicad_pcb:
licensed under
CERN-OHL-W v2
